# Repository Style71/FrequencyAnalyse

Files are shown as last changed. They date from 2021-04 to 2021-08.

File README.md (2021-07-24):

# FrequencyAnalyse

## About

Analyzing three frequency components in an analog signal and transmitting to host using Bluetooth-UART.

This project consists of five independent directories:

- `STM32Firmware`, the firmware of the STM32F767 MCU on the PCB/fPCB, which analyzing three frequency components in an analog signal using FFT, and transmitting the frequency info to host using Bluetooth-UART. The project is a mixture of C, C++ and Assembly language, and it is configured/edited/built/debugged using VScode IDE and build with `make`, see `STM32Firmware/README.md` for detailed description.
- `Hardware`, the PCB projects of the PCB/fPCB board. There are two subdirectories in this directory, `Hardware/SignalAnalyseV1.0` is the PCB project of prototype board, which is used for circuit validation and firmware development; `Hardware/SignalAnalyseV3.0.pdf` is the PCB project of the final fPCB board.
- `JavaProgram`, the Java project for the validation of the communication protocol parsing algorithm, see `JavaProgram/README.md` for detailed description.
- `Simulation`, Multisim simulation project of the envelope detector and bandpass filter circuit.
- `AndroidProject`, the Android program for time-frequency graph plotting and channel enable.
- `Doc`, documents about the signal processing algorithm used in this project, about the code structure and third-party API used in the firmware, about the PCB design consideration and circuit simulation results, and some technical notes during coding.

## Code download

There are two branches in this git repository:

- `master`-- Firmware for SignalAnalyseV1.0 prototype board.
- `V3.0`-- Firmware for SignalAnalyseV3.0 fPCB board, this branch is the final version of the entire project, use this branch as default. 

Use the following command to clone the project to your local host.

```bash
git clone https://github.com/Style71/FrequencyAnalyse.git
git submodule update --init --recursive
git checkout V3.0
```

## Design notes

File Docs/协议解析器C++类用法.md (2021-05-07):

# 协议解析器类用法

位置：`Message.cpp: ProtocolStream`

- 先根据你的程序框架，修改以下函数的具体实现：

  ```cpp
  void putchars(const char *pucArray, int size);
  void recv_frequency_info(uint8_t channel, WavePara &wave);
  void recv_battery_info(BatteryStatus &battery);
  ```

  其中`putchars`实现将指定数量的bytes通过蓝牙发送给下位机；`recv_frequency_info`实现你期望的收到频率报文后的程序行为；`recv_battery_info`实现你期望的收到电池状态报文后的程序行为。

- 将接收到的数据Bytes流输入给函数：

  ```cpp
  uint8_t ParsingMessage(uint8_t *msg, uint8_t len);
  ```

大功告成！

`type.h`文件定义了程序使用到的基本数据结构；

`DataStructure.cpp`/`DataStructure.h`实现了一个队列模板类，用于`ProtocolStream`类中的FIFO。你可以用Java的标准类替换。

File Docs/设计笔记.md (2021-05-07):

# 设计笔记

**注意**：本文描述的固件程序对应`FrequencyAnalyseV3.0`，硬件对应`SignalAnalyseV3.0`。

## 工程中使用`CMSIS-DSP`库

**CMSIS**(Cortex Microcontroller Software Interface Standard)提供了一个Cortex®-M系列处理器使用的通用信号处理函数库**CMSIS-DSP**，函数代码开源，可用两种方式调用：

1. 使用预先编译好的`.Lib`文件
   - 在Keil中点击add package，CMSIS DSP，工程列表里将出现一个...，自动包含对应的库文件。本次设计使用的Cortex-M7内核包含双精度浮点单元，工程使用Little endian顺序，因此使用的库为`arm_cortexM7lfdp_math.lib`(Cortex-M7, Little endian, Double Precision Floating Point Unit);
   - 在使用到CMSIS DSP库中函数的`.cpp`文件中包含头文件
  ```cpp
  #include "arm_math.h"
  ```
2. 自行编译`.Lib`文件，并在工程中包含该库文件
   
   - The library installer contains a project file to rebuild libraries on MDK toolchain in the `CMSIS\DSP_Lib\Source\ARM` folder.
   
     - arm_cortexM_math.uvprojx
   
     The libraries can be built by opening the arm_cortexM_math.uvprojx project in MDK-ARM, selecting a specific target, and defining the optional preprocessor macros detailed above.

### 使用`arm_biquad_cascade_df1_f32`函数注意

使用前需要先调用初始化函数：

```cpp
void arm_biquad_cascade_df1_init_f32(arm_biquad_casd_df1_inst_f32 *S, uint8_t numStages, float32_t *pCoeffs, float32_t *pState)
```

其中结构体`arm_biquad_casd_df1_inst_f32`定义为：

```cpp
typedef struct
{
  uint32_t numStages; /**< number of 2nd order stages in the filter.  Overall order is 2*numStages. */
  float32_t *pState;  /**< Points to the array of state coefficients.  The array is of length 4*numStages. */
  float32_t *pCoeffs; /**< Points to the array of coefficients.  The array is of length 5*numStages. */
} arm_biquad_casd_df1_inst_f32;

```

第一次使用时犯了一个错误，我在滤波器的初始化函数中创建了局部数组`Coeffs`、`initState`，用于初始化定义在全局的滤波器结构体`IIRFilterS`：

```cpp
static arm_biquad_casd_df1_inst_f32 IIRFilterS;

void InitFilter()
{
  float Coeffs[5 * STAGE_NUM];
  const float initState[4 * STAGE_NUM] = {0};
  // Initialise a 11-order Butterworth IIR filter with 120Hz passband and 200Hz stop frequency.
  for (int i = 0; i < STAGE_NUM; i++)
  {
    for (int j = 0; j < 3; j++)
      Coeffs[j + i * 5] = Gain[i] * NUM[i][j] / DEN[i][0];
    Coeffs[3 + i * 5] = -DEN[i][1] / DEN[i][0];
    Coeffs[4 + i * 5] = -DEN[i][2] / DEN[i][0];
  }
  arm_biquad_cascade_df1_init_f32(&IIRFilterS, STAGE_NUM, Coeffs, (float*) initState);
}
```

使用时发现滤波器的输出不正常，DEBUG时观察到`IIRFilterS->pCoeffs`和`IIRFilterS->pState`始终在非人为地改变，一开始还怀疑是DMA的目标地址、传输长度设置不对导致了全局变量`IIRFilterS`发生非人为地改变，后来才注意到`arm_biquad_casd_df1_inst_f32`的定义，`pCoeffs`、`pState`仅仅保留了一个指针，并没有对数据进行硬复制，也没有一个真正存储`pCoeffs`和`pState`的空间，如果我使用局部数组初始化，当`InitFilter()`函数退出后，`Coeffs[5 * STAGE_NUM]`、`initState[4 * STAGE_NUM]`的空间就被销毁了。

正确的使用方式是：定义全局数组用于存放滤波器系数和状态，然后在初始化函数中让指针`pCoeffs`、`pState`指向这两个数组。

```cpp
arm_biquad_casd_df1_inst_f32 IIRFilterS;
static float Coeffs[5 * STAGE_NUM];
static float initState[4 * STAGE_NUM] = {0};

void InitFilter()
{
  // Initialise a 11-order Butterworth IIR filter with 120Hz passband and 200Hz stop frequency.
  for (int i = 0; i < STAGE_NUM; i++)
  {
    for (int j = 0; j < 3; j++)
      Coeffs[j + i * 5] = Gain[i] * NUM[i][j] / DEN[i][0];
    Coeffs[3 + i * 5] = -DEN[i][1] / DEN[i][0];
    Coeffs[4 + i * 5] = -DEN[i][2] / DEN[i][0];
  }
  arm_biquad_cascade_df1_init_f32(&IIRFilterS, STAGE_NUM, Coeffs, initState);
}
```

这种实现方法就很奇怪，封装得不够好，要是使用者不清楚函数的实现，就很容易出错。虽然在滤波器实现之前，编程者并不知道滤波器有几阶，由于没有堆空间，不能使用动态内存分配，所以定义结构体`arm_biquad_casd_df1_inst_f32`时并不能指定`pCoeffs`、`pState`的数组大小，但是，滤波器的阶数完全可以在编译时确定，因此可以使用宏定义在编译时分配好`pCoeffs`、`pState`的空间。

### 使用`arm_rfft_fast_f32`函数注意

使用前需要先调用初始化函数：

```cpp
arm_status arm_rfft_init_f32(arm_rfft_instance_f32 *S, arm_cfft_radix4_instance_f32 *S_CFFT, uint32_t fftLenReal, uint32_t ifftFlagR, uint32_t bitReverseFlag)
```

初始化方式为：

```cpp
arm_rfft_fast_instance_f32 S;

void some_function()
{
    if (arm_rfft_fast_init_f32(&S, N) == ARM_MATH_ARGUMENT_ERROR)
        Error_Handler();
}
```

注意结构体`arm_rfft_fast_instance_f32`一定要放在全局，

## 计时器TIM的使用

本工程仅使用一个32-bit 的计时器TIM2，用于产生一个4kHz的方波信号作为**ADC1**的采样触发信号。具体配置如下：

- 

## STM32 使用DMA传送ADC转换数据

本例程使用**TIM2**产生一个4kHz的方波信号作为**ADC1**的采样触发信号，ADC工作在单次采样模式下，采样完成后结果由**DMA2**传送到FIFO中，直至FIFO容量达到3/4时转存到数据保存区`ADCBuffer0[ADC_BUFFER_SIZE]`和`ADCBuffer1[ADC_BUFFER_SIZE]`中，DMA工作在Double buffer mode下，双缓存模式将自动使能Circular mode，在该模式下，当传输计数器`DMA_SxNDTR `降至0后，会自动重载到设定值，同时DMA目标地址切换到另一个buffer。

第一次配置使用时发现：开始运行ADC后，`DMA_SxNDTR` 逐渐降至0并自动重载到设定值`ADC_BUFFER_SIZE`，然而却再也不会下降，FIFO、buffer中的数据也不再更新。此时重新发起ADC转换，DMA也不会传送数据。仔细阅读Manual，发现ADC的控制寄存器`ADC_CR2`的bit 9 `DDS `控制DMA计数至0后ADC是否继续产生新的传送请求：

At the end of the last DMA transfer (number of transfers configured in the DMA controller’s DMA_SxNTR register):

- No new DMA request is issued to the DMA controller if the DDS bit is cleared to 0 in the ADC_CR2 register (this avoids generating an overrun error). However the DMA bit is not cleared by hardware. It must be written to 0, then to 1 to start a new transfer. 
- Requests can continue to be generated if the DDS bit is set to 1. This allows configuring the DMA in double-buffer circular mode.

在使用**HAL**库时，若要使能`DDS`位，需要作如下初始化：

```cpp
hadc1.Init.DMAContinuousRequests = ENABLE;
```

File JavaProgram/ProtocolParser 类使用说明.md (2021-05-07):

# ProtocolParser 类使用说明

## 功能描述

- `ProtocolParser`类实现了对满足`FrequencyAnalyseV3.0`协议规范的数据流的**连接**、**解析**与**校验**;
- 封装了报文发送函数，可以方便地使用`ProtocolParser`类接口函数，**发送**满足协议规范的报文。

## 函数接口

### 类构造函数

- ```java
  public ProtocolParser();
  ```
  类构造函数，程序开始时创建类的实例即可:
  
  ```java
  ProtocolParser parser = new ProtocolParser();
  ```
  
  一个数据流可以同时feed多个解析类，但一个解析类只用于一个数据流的解析。
  
### 数据接收相关函数

- ```java
  public byte ParsingMessage(byte[] msg, int len) 
  ```
  数据输入流解析函数。该函数获取数据流输入，每次的输入数据可以是任意长度的byte，可以是截断的报文，只要输入的byte是**保序**的，函数内部会对输入数据进行缓存和连接；当确认接收到一个完整报文时，函数会自动解析报文，校验报文正确性，并调用对应报文的接收处理函数，见下表：
  
  | 报头                   | 报文内容              | 调用函数名                                              |
  | ---------------------- | --------------------- | ------------------------------------------------------- |
  | `0x51`、`0x52`、`0x53` | 3个频率通道的频率数据 | `void frequency_callback(int channel, WavePara freq)`   |
  | `0x59`                 | 电池电量状态          | `void battery_callback(BatteryStatus Batt)`             |
  | `0x5F`                 | 3个频率通道的使能指令 | `void channel_enable_callback(boolean[] channelEnable)` |
  使用该函数时，只需将输入数据流以`byte[]`形式传递给函数，为应对并非`byte[]`中所有`byte`均为有效数据的情况，需要在函数第二个参数中指定输入的`byte[]`包含的有效数据长度，用法如下：
  
  ```java
  BufferedInputStream binInput = new BufferedInputStream(new FileInputStream("Data.dat"));
  ProtocolParser parser = new ProtocolParser();
  int byteRead;
  byte[] msg;
  
  while ((byteRead = binInput.available()) > 0) {
      msg = binInput.readNBytes(byteRead);
      parser.ParsingMessage(msg, byteRead);
  }
  ```
  
- ```java
  private void frequency_callback(int channel, WavePara freq)
  ```
  接收到一帧频率报文时回调的函数，使用时在该函数内部实现收到该报文时需要做出的响应。传入的数据类`WavePara`封装了通道`channel`（1~3）的频率信息。`WavePara`类定义如下：
  
  ```java
  class WavePara {
      public int t;
      public float freq;
      public float mag;
      public float freq_deriv;
  
      public WavePara() {
          t = 0;
          freq = 0;
          mag = 0;
          freq_deriv = 0;
      }
  };
  ```
  
- ```java
  private void battery_callback(BatteryStatus Batt)
  ```
  接收到一帧电池电量状态报文时回调的函数，使用时在该函数内部实现收到电量报文时需要做出的响应。传入的数据类`BatteryStatus`封装了所有电池的电量状态信息。`BatteryStatus`类定义如下：
  
  ```java
  class BatteryStatus {
      public int t;
      public short voltage;
      public short current;
      public byte capacity;
  
      public BatteryStatus() {
          t = 0;
          voltage = 0;
          current = 0;
          capacity = 0;
      }
  };
  ```
  
- ```java
  private void channel_enable_callback(boolean[] channelEnable)
  ```
  接收到一帧电池电量状态报文时回调的函数。该函数供嵌入式系统调用，响应手机端上位机发来的通道使能指令，Android端可不关注，保持该函数为空。
  
### 数据发送相关函数
- ```java
  public void send_channel_enable_info(boolean[] channelEnable) 
  ```
  以协议格式发送3个频率通道的使能指令报文。该函数由Android端上位机调用，`channelEnable[i] == false`时，接收到报文的下位机将禁能频率通道`i`，不再发送该通道的频率数据；`channelEnable[i] == true`时可再次使能。

- ```java
  public void send_frequency_info(int channel, WavePara wave)
  ```
  以协议格式发送3个频率通道的频率数据报文。该函数由嵌入式端调用，Android端不调用。
  
- ```java
  public void send_battery_info(BatteryStatus battery)
  ```
  以协议格式发送电池电量状态报文。该函数由嵌入式端调用，Android端不调用。
  
- ```java
  private void putc_callback(byte[] msg)
  ```
  输出数据流的实现函数。前文提及的3个报文发送函数都依赖于本函数实现字节流的发送。需要由函数使用者实现发送数据流的功能。输出数据存放于`byte[] msg`数组中，长度为`msg.length`，待发送的数据低地址先发送，高地址后发送，`msg[0]`->`msg[msg.length]`。

## 用法说明

对于Android端上位机，只**需实现**以下函数：

```java
private void frequency_callback(int channel, WavePara freq);
private void battery_callback(BatteryStatus Batt);
private void putc_callback(byte[] msg);
```

Android端与嵌入式端的数据流如下图：

ProtocolParser类信息流示意图

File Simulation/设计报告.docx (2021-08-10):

带通滤波器参数：

R_1 =1MΩ ， R_2 =10kΩ ， C_1 =160nF ， C_2 =4nF ，低截止频率 f_L =2πR_1 C_1 ≈1Hz ，高截止频率 f_H =2πR_2 C_2 ≈4kHz , 中心频率 f_C =√(f_L ∙f_H)≈63Hz 。

电压传递函数 H(s)=(R_1 C_1 s)/((R_1 R_2 C_1 C_2 )s^2 +(R_1 C_1 +R_1 C_2 +R_2 C_2 )s+1)

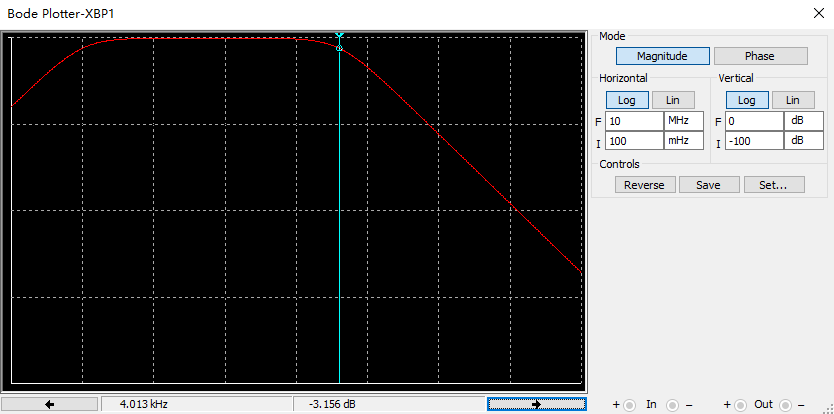
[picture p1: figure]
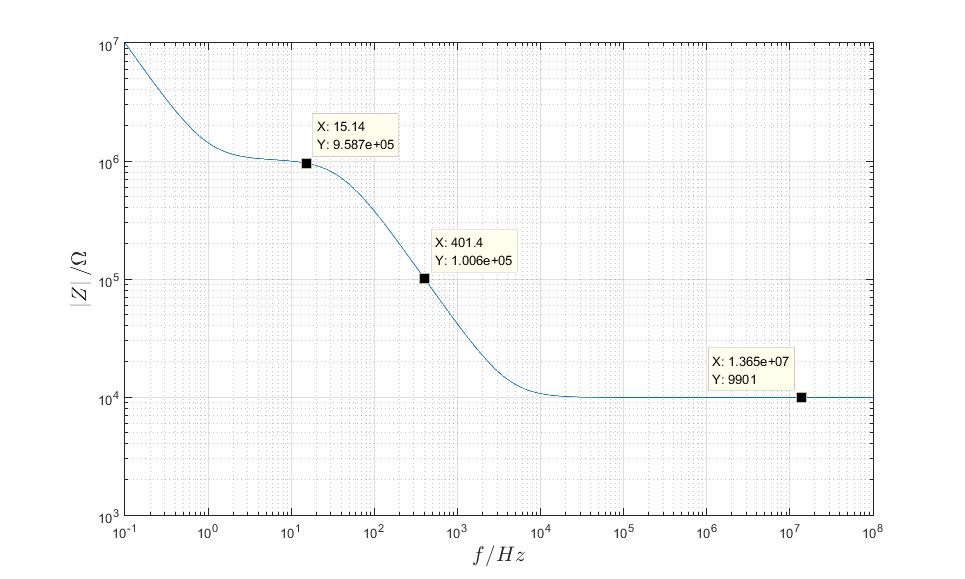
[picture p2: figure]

设采样频率 f_s =5kHz ，采样时窗 1s ，采样的同时计算前一秒数据FFT，采样数据按照double类型存储，保守估计需要 f_s ×8×4≈160kB 内存。

设采样频率为 f_s ，采样时窗为 T ，则采样点数 n=T∙f_s ，频率分辨率 δf=(f_s)/n=1/T ，即不确定性原理：信号频率不确定性 δf 与信号出现时间的不确定性 T 的乘积为常数。

T∙δf=1

假设一秒内需要对信号进行 k 次频率计算，则 T=1/k ， δf=k 。

设计要求以及对应的频率精度为：

信号频率 f | 采样时窗 T | 计算频率 k | 频率分辨率 δf
15~35Hz | 10s | 0.1 | 0.1Hz
60~100Hz | 2s | 0.5 | 0.5Hz
200~400Hz | 0.1s | 10 | 10Hz

若先验地认为信号频率变化缓慢，则可以将 T 提升，以降低 δf 。

f_s =4kHz

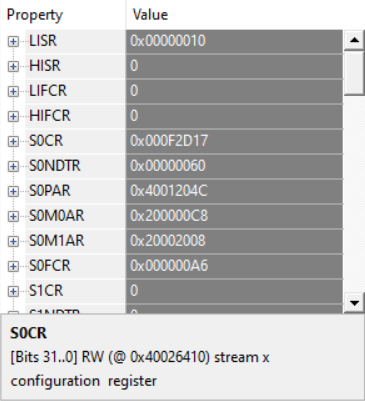
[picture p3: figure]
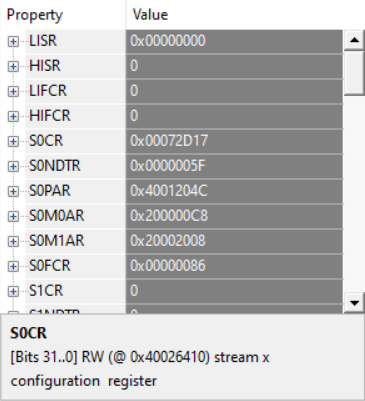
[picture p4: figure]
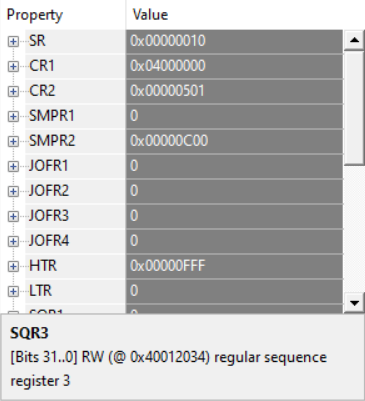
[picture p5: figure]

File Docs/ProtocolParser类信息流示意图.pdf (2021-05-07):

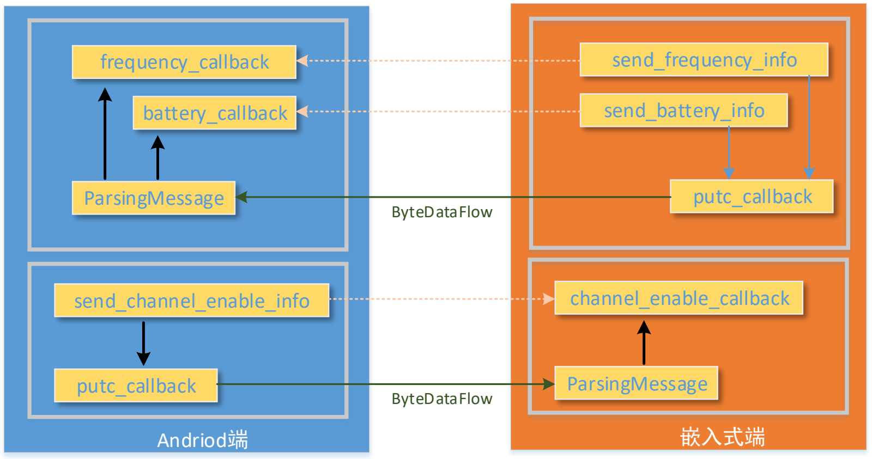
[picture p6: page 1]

Andriod

端 | 嵌入式端

putc

_callback

send

_channel

_enable

_info

putc

_callback

send

_frequency

_info

battery

_callback | send _battery

_info

frequency

_callback

ParsingMessage

ParsingMessage

channel

_enable

_callback

ByteDataFlow

ByteDataFlow

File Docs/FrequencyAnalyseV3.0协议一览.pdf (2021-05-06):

Head | Payload | Checksum | Type | TX Period | Note
byte[0] byte[1] byte[2] byte[3] byte[4] byte[5] byte[6] byte[7] byte[8] byte[9] byte[10] byte[11] byte[12] byte[13] byte[14] byte[15] byte[16] byte[17] byte[18]
System time/us | Frequency/Hz | Magnitude/V | Frequency Derivation/Hz
0x5A | 0x51 | uint32_t | float | float | float | bit XOR | 主动发送报文 0.128s | 180~420Hz Frequency Channel 1
0x5A | 0x52 | uint32_t | float | float | float | bit XOR | 主动发送报文 2.56s | 50~120Hz Frequency Channel 2
0x5A | 0x53 | uint32_t | float | float | float | bit XOR | 主动发送报文 10.24s | 10~40Hz Frequency Channel 3
Head | Payload | Checksum | Type | TX Period | Note
byte[0] byte[1] byte[2] byte[3] byte[4] byte[5] byte[6] byte[7] byte[8] byte[9] | byte[10] | byte[11]
System time/us | Voltage/mV | Current/mA Capacity/percent
0x5A | 0x59 | uint32_t | uint16_t | uint16_t | uint8_t | bit XOR | 主动发送报文 | 1.00s | 系统电量使用情况
Head | Payload | Checksum | Type | Note
byte[0] byte[1] | byte[2] | byte[3] | byte[4] | byte[5]
Channel 1 Enable Channel 2 Enable Channel 3 Enable
0x5A | 0x5F | uint8_t | uint8_t | uint8_t | bit XOR | 接收报文 | 通道使能字节，1：使能，0：禁能
1.报文采用Little Endian模式发送、接收，先发送低位字节，再发送高位字节，byte[0]->byte[n]； 2.数据段低位在前，高位在后，例如uint32_t类型的System time，其值为2760643741（0xA48C149D），byte[2]=0x9D，byte[5]=0xA4； 3.数据校验位Checksum为Head+Payload所有位的异或XOR。

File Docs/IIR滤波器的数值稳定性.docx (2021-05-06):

IIR滤波器的数值稳定性

在微控制器上实现同一个IIR（Infinite Impulse Response，无限冲激响应）滤波器时，不同的实现方式可能出现不同的数值稳定性问题，对于部分病态情况，会导致滤波器输出严重偏离真实值。现举例来说：

系统采样率 f_s =4kHz ，欲设计一个LPF（Low Pass Filter，低通滤波器），通带频率 f_p =120Hz ，截止频率 f_(stop) =200Hz ，截止频率衰减 A_(stop) =40dB 。令 u[n] 表示输入， y[n] 表示输出，对应的频域表示分别为 U(z) 、 Y(z) 。使用Matlab fdatool 给出一个11阶的Butterworth滤波器：

(Y(z))/(U(z))=H(z)=G(a_0 +a_1 z^(-1) +⋯+a_11 z^(-11))/(b_0 +b_1 z^(-1) +⋯+b_11 z^(-11)) (1-1)

其中，分子系数 a=[1, 11, 55, 165, 330, 462, 462, 330, 165, 55, 11, 1] ，

分母 b=[, 1.0000, -9.5923, 41.9040, -110.0381, 192.9809, -237.3184,, 208.8062, -131.4397, 58.0076, -17.0926, 3.0264, -0.2439]

增益 G=5.2262×10^(-12) 。

频率响应、单位冲击响应如图.1-a、图.1-b：

图.1-a 频率响应 H(z)

图.1-b 单位冲击响应 h[n]

该IIR滤波器的时域表示为：

b_0 y[n]+b_1 y[n-1]+⋯+b_11 y[n-11]

=G(a_0 u[n]+a_1 u[n-1]+⋯+a_11 u[n-11]) (1-2)

第一种滤波器的实现方法，可根据递推关系式(1-2)，使用 22 个中间状态值临时存储 y[n-1], y[n-2],⋯, y[n-11],u[n-1], u[n-2], ⋯,u[n-11] ，实现该IIR滤波器。

另一种是状态空间实现方案。该11阶Butterworth滤波器只有11个独立状态，令 x[n]∈R^11 ，采用可控标准型实现：

{x[n+1]=Ax[n]+Bu[n]y[n]=Cx[n]+Du[n] (1-3)

其中 A∈R^(11×11) ， B∈R^(11×1) ， C∈R^(1×11) ， D∈R^(1×1) ，

A=[-(b_1)/(b_0), -(b_2)/(b_0), -(b_3)/(b_0)1, 0, 00, 1, 0, ⋯, -(b_10)/(b_0), -(b_11)/(b_0)0, 00, 0⋮, ⋱, ⋮0, 0, 00, 0, 0, ⋯, 0, 01, 0] ， B=[1, 0, 0⋯0, 0, 0]^T ，

C=G[a_1 -(a_0)/(b_0)b_1 , a_2 -(a_0)/(b_0)b_2 , a_3 -(a_0)/(b_0)b_3 ⋯a_9 -(a_0)/(b_0)b_9 , a_10 -(a_0)/(b_0)b_10 , a_11 -(a_0)/(b_0)b_11 ] ，

D=G(a_0)/(b_0)

计算得出 A 的第一行

A(1,:)=[, 9.5923, -41.9040, 110.0381, -192.9809, 237.3184, -208.8062, , 131.4397, -58.0076, 17.0926, -3.0264, 0.2439] 。

采用该状态空间实现方案，在Cortex-M7内核芯片上使用C++实现，数值类型采用32bit float，计算单位冲激响应 h[n] ，发现 h[n] 很快以指数发散了，如图.2。由于 u[n]=δ[n] ，由式(1-3)知， h[n] 发散意味着 x[n] 发散了，将 x_1 [n] 绘出，如图.3。

图2. 使用状态空间实现的IIR滤波器，其单位冲击响应 h[n]

图3. 单位冲击 δ[n] 下的状态变化 x_1 [n]

由于 x[1]=[1, 0, 0⋯0, 0, 0]^T ， u[n]=0 (n≥1) ，故 x[n+1]=A^n x[1]=A^n (:,1) ， x[n+1] 发散意味着矩阵 A^n 的第一列发散了。将 A 分解为Jordan标准型，

A=P∙J∙P^(-1) ，A^n =P∙J^n ∙P^(-1)

J^n =[J_1^n , ⋯, 0⋮, ⋱, ⋮0, ⋯, J_k^n ] ， J_i^n =[λ_i^n , C_n^1 λ_i^(n-1) , C_n^2 λ_i^(n-2) 0, λ_i^n , C_n^1 λ_i^(n-1) 0, 0, λ_i^n , ⋯, C_n^(m-1) λ_i^(n-m+1) C_n^(m-2) λ_i^(n-m+2) C_n^(m-3) λ_i^(n-m+3) ⋮, ⋱, ⋮0, 0, 0, ⋯, λ_i^n ]_(m×m)

A^n 发散也即 A 存在大于 0 的特征值。事实真的如此吗？使用Matlab计算 A 的Jordan标准型分解：

>> [P,J]=jordan(A)

得到 A 的 11 个特征值：

λ=[, 0.8173, 0.8229±0.0471i, 0.8395±0.0922i, 0.8670±0.1331i,, 0.9052±0.1672i, 0.9530±0.1916i]

模 |λ_i | 竟然均小于1！如果使用Matlab采用 P∙J^n ∙P^(-1) 计算 A^n ，发现 A^n 也是收敛的；而若直接用Matlab指令A^n计算 A^n ，结果发散……

基于如下原因，更倾向于相信 P∙J^n ∙P^(-1) 的计算结果：

- 使用 A^n =P∙J^n ∙P^(-1) 计算 x[n+1] ，进而计算 y[n+1]=Cx[n+1] ，得到的结果与Matlab计算的单位冲激响应 h[n] 结果一致；
- 理论上使用 A^n =P∙J^n ∙P^(-1) 方式的计算结果具有更高的数值稳定性。

那为何使用微控制器、Matlab的A^n指令直接计算 A^n 结果发散了？原因在于矩阵 A 病态(ill-conditioned)。使用矩阵奇异值分解计算 A 的奇异值：

A=PΣQ

Σ=[σ_1 , 00, σ_2 , ⋯, 00⋮, ⋱, ⋮0, 0, ⋯, σ_11 ] ， σ_1 =414.8 ， σ_2 =σ_3 =⋯=σ_10 =1 ， σ_11 =5.88×10^(-4) ，

PP^T =QQ^T =I_11

矩阵 A 的条件数 cond(A)=7.0543×10^5 。由于变量使用浮点数存储、计算存在舍入误差，设 x[n+1]=A[x[n]+δx[n]]=x[n+1]+Aδx[n] ，计算相对误差增量的上界

sup(‖δx[n+1]‖)/(‖x[n+1]‖)=sup(‖Aδx[n]‖)/(‖Ax[n]‖)=(sup‖Aδx[n]‖)/(inf‖Ax[n]‖)=(σ_1 ‖δx[n]‖)/(σ_11 ‖x[n]‖)=cond(A)(‖δx[n]‖)/(‖x[n]‖)

因此每次计算矩阵乘法，将可能使状态变量 x[n] 的相对误差增加 cond(A) 倍。

如果换用递推关系式(1-2)的实现方案呢？此时计算过程等价于选取状态变量 x[n]=[u[n-1], u[n-2], ⋯,u[n-11], y[n-1], y[n-2],⋯, y[n-11]]∈R^22 ，

A=[0_(1×11) I_10 , 0_(10×1) , 0_(11×11) G/(b_0)a(2:11)0_(10×11) , -1/(b_0)b(2:11)I_10 , 0_(10×1) ]

此时 rank(A)=21 ， A 的奇异值为： σ_1 =414.8 ， σ_2 =σ_3 =⋯=σ_20 =1 ， σ_21 =5.88×10^(-4) ， cond(A)=7.0543×10^5 。当 n≥12 后， x_1 [n]=⋯=x_11 [n]=0 ，计算过程变为了：

{x(12:22)[n+1]=A(12:22,12:22)x(12:22)[n]y[n]=x(12)[n]

此时的 A(12:22,12:22) 就是上一种方式中的 A ，仅仅改变了状态变量为输出变量，按照之前的分析，这种实现方式与第一种相比并没有改善数值稳定性，也是有可能发散的。

当然，使用Matlab计算的结果， y[n] 是收敛的；第一种方案在Cortex-M7内核芯片上采用64bit double数值类型计算，结果也是收敛的。然而，没有改变问题本身的数值特性，仅依靠提高运算精度，算法是不可靠的。

合适的做法是将传递函数分解为多个二阶传递函数的乘积。如本问题，可以分解为5个二阶滤波器和1个一阶滤波器的级联，每个滤波器的传递函数为：

H_i (z)=(b_(i0) +b_(i1) z^(-1) +b_(i2) z^(-2))/(1-a_(i1) z^(-1) -a_(i2) z^(-2))

实现时使用 u[n-1], u[n-2],y[n-1], y[n-2] 作为状态变量以提高数值稳定性，这种实现方案在CMSIS-DSP库中被称为“Biquad Cascade IIR Filters Using Direct Form I Structure”，如图4所示。

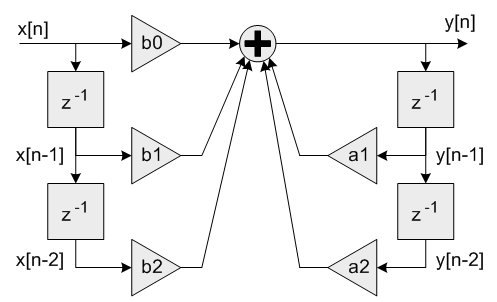
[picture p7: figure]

图4. 二阶IIR滤波器Direct Form I结构

6个滤波器的系数分别为：

a_i =[1, 2, 1] ， i=1, 2,⋯,5 ， a_6 =[1, 1] ；

b_1 =0.01043620054×[1, -1.901244521, 0.9429892898] ，

b_2 =0.009894934483×[1, -1.802637815, 0.842217505] ，

b_3 =0.009464552626×[1, -1.72423172, 0.7620899677] ，

b_4 =0.009154595435×[1, -1.667764425, 0.7043827772] ，

b_5 =0.00896828156×[1, -1.633822203, 0.6696953177] ，

b_6 =0.09437258542×[1, -0.8112547994] 。

若从状态空间的角度看计算过程，每个滤波器的系数矩阵 A_i 为：

A_i =[0, 01, 0, 0, 00, 0b_(i1) , b_(i2) 0, 0, a_(i1) , a_(i2) 1, 0]

计算每个矩阵 A_i （ i=1,2,⋯,5 ）的右下子阵 A_i (3:4,3:4) 的条件数，分别为：

Cond(A_1 (3:4,3:4))=5.66 ，

Cond(A_2 (3:4,3:4))=5.71 ，

Cond(A_3 (3:4,3:4))=5.80 ，

Cond(A_4 (3:4,3:4))=5.90 ，

Cond(A_5 (3:4,3:4))=5.98 。

该计算问题是良态的。

思考：

使用 n 个2阶矩阵级联构成一个 2n 阶的滤波器，内部独立的状态变量仍然只有 2n 个，整个计算过程可以用一个 2n 阶的状态方程等效替代。对于所有 2n 阶的状态空间实现，由于都是最小实现，相互间可以用一个非奇异线性变换相互转化， A=T^(-1) AT 。因此原方案是病态的，之所以换用Direct Form I结构实现后变为良态的，就是使用了一个变换 T ，使得条件数 cond(A)=cond(T^(-1) AT) 显著降低。

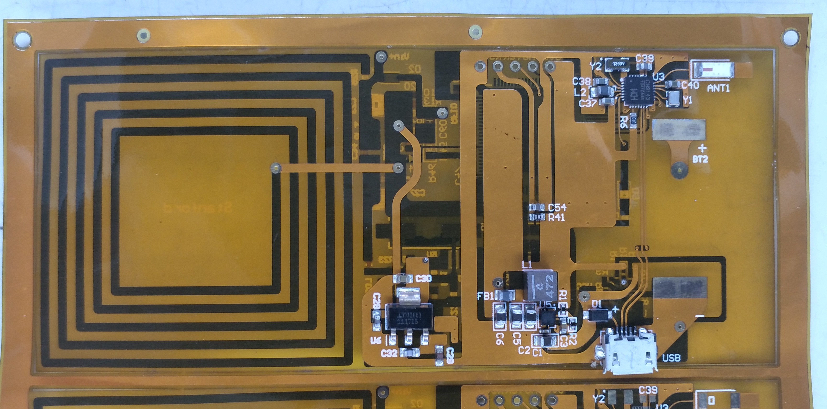
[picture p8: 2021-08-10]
Hardware/SignalAnalyseV3.0/T-N48W156855A-02.jpg

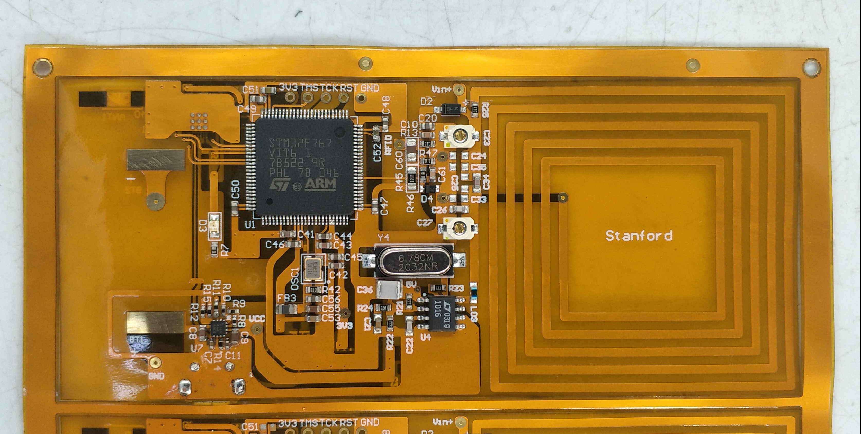
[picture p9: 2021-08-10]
Hardware/SignalAnalyseV3.0/T-N48W156855A-01.jpg

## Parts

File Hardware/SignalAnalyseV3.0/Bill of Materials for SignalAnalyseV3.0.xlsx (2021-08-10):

Designator | Comment | Description | Footprint | Manufacturer | Part Number | Quantity
C4, C5, C6 | Cap 47μF | 多层陶瓷电容器MLCC - SMD/SMT 0805 10V 47uF X5R 20% T: 1.25mm | 0805 | TDK | C2012X5R1A476M125AC | 3
C1 | Cap 22μF | 多层陶瓷电容器MLCC - SMD/SMT 0805 35VDC 22uF 20% X5R 1.25mm | 0805 | TDK | C2012X5R1V226M125AC | 1
C2 | Cap 2.2nF | 多层陶瓷电容器MLCC - SMD/SMT 0402 2200pF 50volts X7R 10% | 0402 | MuRata | GRM155R71H222KA01D | 1
C7 | Cap 1.3nF | 多层陶瓷电容器MLCC - SMD/SMT 0402 1.3nF 50VDC X7R 5% | 0402 | MuRata | GRM155R71H132JA01D | 1
C11 | Cap 100nF | 多层陶瓷电容器MLCC - SMD/SMT 0402 100nF 10VDC X5R 5% | 0402 | MuRata | GRM155R61A104JA01D | 1
C3 | Cap 470nF | 多层陶瓷电容器MLCC - SMD/SMT 0603 0.47uF 6.3volts X5R 10% | 0603 | MuRata | GRM188R60J474KA01D | 1
C61 | Cap 33nF | 多层陶瓷电容器MLCC - SMD/SMT 0603 0.033uF 6.3volts U2J 5% | 0603 | MuRata | GRM1887U0J333JA01D | 1
C10 | Cap 47nF | 多层陶瓷电容器MLCC - SMD/SMT 47nF+/-10% 50V X7R 1608 | 0603 | SAMSUNG | CL10B473KB8NNNC | 1
C20 | Cap 100nF | 多层陶瓷电容器MLCC - SMD/SMT 100nF+/-10% 50V X7R 1608 | 0603 | SAMSUNG | CL10B104KB8NNNC | 1
C21 | Cap 820p | 多层陶瓷电容器MLCC - SMD/SMT 0603 820pF 100volts X7R 5% | 0603 | MuRata | GRM188R72A821JA01D | 1
C22 | Cap 200p | 多层陶瓷电容器MLCC - SMD/SMT 0603 200pF 100volts C0G 2% | 0603 | MuRata | GRM1885C2A201GA01D | 1
C23, C27 | Cap Var | Trimmer Capacitors - Ceramic Dielectric, 8 pF to 40 pF, 350 V | Variable_Capacitor_JZ400HV1 | Knowles | JZ400HV | 2
C24, C25 | Cap 100pF | 多层陶瓷电容器MLCC - SMD/SMT 0201 100pF 50volts C0G +/-2% | 0603 | MuRata | GRM0335C1H101GA01D | 2 | Capacitor_for resonance | 无需贴片
C26 | Cap 300pF | 多层陶瓷电容器MLCC - SMD/SMT 0603 300pF 50volts C0G 2% | 0603 | MuRata | GRM1885C1H301GA01D | 1 | Capacitor_for resonance
C34 | Cap 33pF | 多层陶瓷电容器MLCC - SMD/SMT 0603 33pF 50volts C0G 5% | 0603 | MuRata | GRM1885C1H330JA01J | 1 | Capacitor_for resonance
C33, C35 | Cap 0~200pF | Do not place | 0603 |  |  | 2 | Capacitor_for resonance
C28, C39, C44, C45, C46, C47, C48, C49, C50, C54, C56 | Cap 100nF | 多层陶瓷电容器MLCC - SMD/SMT 0.1UF 16V 10% 0603 | 0603 | MuRata | GCM188R71C104KA37J | 11
C9, C29, C55 | Cap 10μF | 多层陶瓷电容器MLCC - SMD/SMT 10UF 25V 10% 0603 | 0603 | MuRata | GRM188R61E106KA73D | 3
C30 | Cap 22u | 多层陶瓷电容器MLCC - SMD/SMT 22UF 10V 20% 0603 | 0603 | MuRata | GRM187R61A226ME15J | 1
C32 | Cap 10n | 多层陶瓷电容器MLCC - SMD/SMT 0.01UF 25V 5% 0603 C0G | 0603 | MuRata | GRM1885C1E103JA01D | 1
C36 | Cap 100nF | 多层陶瓷电容器MLCC - SMD/SMT MLCC,1210,C0G,50V,0.1uF,2.5mm | 1210 | TDK | C3225C0G1H104JT000N | 1
C8, C41, C42, C43 | Cap 1μF | 多层陶瓷电容器MLCC - SMD/SMT 0603 1uF 25V X6S 10% | 0603 | MuRata | GRM188C81E105KAADD | 4
C53 | Cap 4.7μF | 多层陶瓷电容器MLCC - SMD/SMT 0603 4.7uF 25V X5R 20% | 0603 | MuRata | GRM188R61E475ME11J | 1
C37, C38, C40, C51, C52 | Cap 2.2μF | 多层陶瓷电容器MLCC - SMD/SMT CGA 0603 16V 2.2uF X5R 10% AEC-Q200 | 0603 | TDK | CGA3E1X5R1C225K080AC | 5
C60 | Cap 22μF | 多层陶瓷电容器MLCC - SMD/SMT 0805 25VDC 22uF 20% X5R 1.25mm | 0805 | TDK | C2012X5R1E226M125AC | 1
D1 | Diode | Surface Mount Schottky Power Rectifier, 1.0 AMPERES 20 VOLTS | SODFL3616X98N | ON Semiconductor | MBR120VLSFT1G | 1
D2 | Diode | Surface Mount Schottky Power Rectifier, 0.5 AMPERES 40 VOLTS | SOD3716X135N | ON Semiconductor | MBR0540T1G | 1
D3 | LED-Green | Green LEDs, 2V 20mA 570 nm | 0805 | Wurth Elektronik | 150080VS75000 | 1
D4 | TDZ3V0J | Zener Diode 3V | SOD323F | Nexperia | TDZ3V0J,115 | 1
FB1, FB3 | Ferrite Bead, 20Ohm@100MHz | WE-CBA SMT EMI Suppression Ferrite Bead | BEADC2012X110N | Wurth Elektronik | 782853200 | 2
L1 | Inductor 4.7 μH | Coilcraft Shielded Power Inductors | XGL4030 | Coilcraft | XGL4030-472MEC | 1
L2 | Inductor 22 μH | Multilayer Chip Ferrite Large Current Inductor | 0805 | microgate | MGFL2012F220 | 1
L03 | Inductor 220 nH | Chip Coils Inductor | 0603 | Murata | LQW18ANR22G00D | 1
R1 | Res 14.7KΩ ±1% | Resistor | 0402 | Vishay-Dale | CRCW040214K7FKED | 1
R2 | Res 4.7KΩ ±1% | Resistor | 0402 | Vishay-Dale | CRCW04024K70FKED | 1
R8 | Res 360KΩ ±1% | Resistor | 0402 | YAGEO | RC0402FR-07360KL | 1
R9 | Res 56KΩ ±1% | Resistor | 0402 | YAGEO | RC0402FR-0756KL | 1
R10 | Res 42.2KΩ ±1% | Resistor | 0402 | YAGEO | RC0402FR-0742K2L | 1
R11 | Res 47KΩ ±1% | Resistor | 0402 | YAGEO | RC0402FR-0747KL | 1
R12 | Res 147KΩ ±1% | Resistor | 0402 | YAGEO | RC0402FR-07147KL | 1
R14 | Res 2.2KΩ ±1% | Resistor | 0402 | YAGEO | RC0402FR-072K2L | 1
R15 | Res 34KΩ ±1% | Resistor | 0402 | YAGEO | RC0402FR-0734KL | 1
R13 | Res 12.7KΩ ±1% | Resistor | 0603 | YAGEO | RC0603FR-0712K7L | 1
R6 | Res 100KΩ ±1% | Resistor | 0603 | YAGEO | RC0603FR-07100KL | 1
R7, R42, R46 | Res 1KΩ ±1% | Resistor | 0603 | YAGEO | RC0603FR-071KL | 3
R21, R22, R23 | Res 2.2KΩ ±1% | Resistor | 0603 | YAGEO | RC0603FR-072K2L | 3
R24 | Res 22Ω ±1% | Resistor | 0603 | YAGEO | RC0603FR-0722RL | 1
R25 | Res 1Ω ±1% | Resistor | 0603 | YAGEO | RC0603FR-071RL | 1
R45 | Res 12KΩ ±2% | Resistor | 0805 | YAGEO | RC0805FR-0712KL | 1
R41, R47 | Res 10KΩ ±1% | Resistor | 0603 | YAGEO | RC0603FR-0710KL | 2
U1 | STM32F767VIT6 | ARM MCU 32-BITS | LQFP-100 | ST | STM32F767VIT6 | 1
U3 | CH9143 | Bluetooth-LowEnergy & UART & USB Mutual Transport | QFN28_4X4 | WCH | CH9143 | 1 | 预量产样片，需从南京沁恒WCH官网购买
U4 | LT1016 | Ultra Fast Precision Comparator | SOIC 8-Lead | Linear Technology/Analog Devices | LT1016CS8#PBF | 1
U5 | XPS62912RPUR | 3-V to 17-V, 2-A/3-A Low Noise and Low Ripple Buck Converter with Integrated Ferrite Bead Filter Compensation | VQFN-HR 1mm | Texas Instruments | XPS62912RPUR | 1 | 预量产样片，需从TI官网购买
U6 | LT1117IST-5#PBF | 800mA Low Dropout Positive Regulators Fixed 5V | SOT-223 | Linear Technology/Analog Devices | LT1117IST-5#PBF | 1
U7 | LM73100RPWR | 2.7 - 23 V, 5.5 A Integrated Ideal Diode with Input Reverse Polarity and Overvoltage Protection | VQFN-HR-10_2X2_TEX | Texas Instruments | LM73100RPWR | 1
ANT1 | Ceramic Antenna | 2.4GHz Antenna - 2.4GHz, 5GHz, Bluetooth, WiFi, WLAN, Zigbee | ANTC5020 | Johanson | 2450AT42A100E | 1
USB | Micro USB Jack | USB连接器 Micro USB Type AB Connectors | Jack (Female) | Wurth Elektronik | 629105150921 | 1
OSC1 | 16MHz | 标准时钟振荡器 SMD XTAL OSC 16MHZ +/-50PPM -40~105C 250TR | SMD/SMT_3.2X2.5 | SEIKO EPSON | SG-310SCF 16.0000ML | 1
Y1 | 32MHz | Quartz Crystal Units YSX211SL 32MHZ-10PF-10PPM | SMD2016-4N | Yangxing Tech | X201632MMB4SI | 1
Y2 | 32.768KHz | Crystal Oscillator FC-135 32.768000KHZ-12.5PF-20PPM | FC-135 | SEIKO EPSON | Q13FC1350000400 | 1
Y4 | 6.78MHz | Industry standard SMD crystal HC49/4HSMX 6.780MHZ-20PF-30PPM | HC49/4HSMX | IQD | LFXTAL057410Bulk | 1

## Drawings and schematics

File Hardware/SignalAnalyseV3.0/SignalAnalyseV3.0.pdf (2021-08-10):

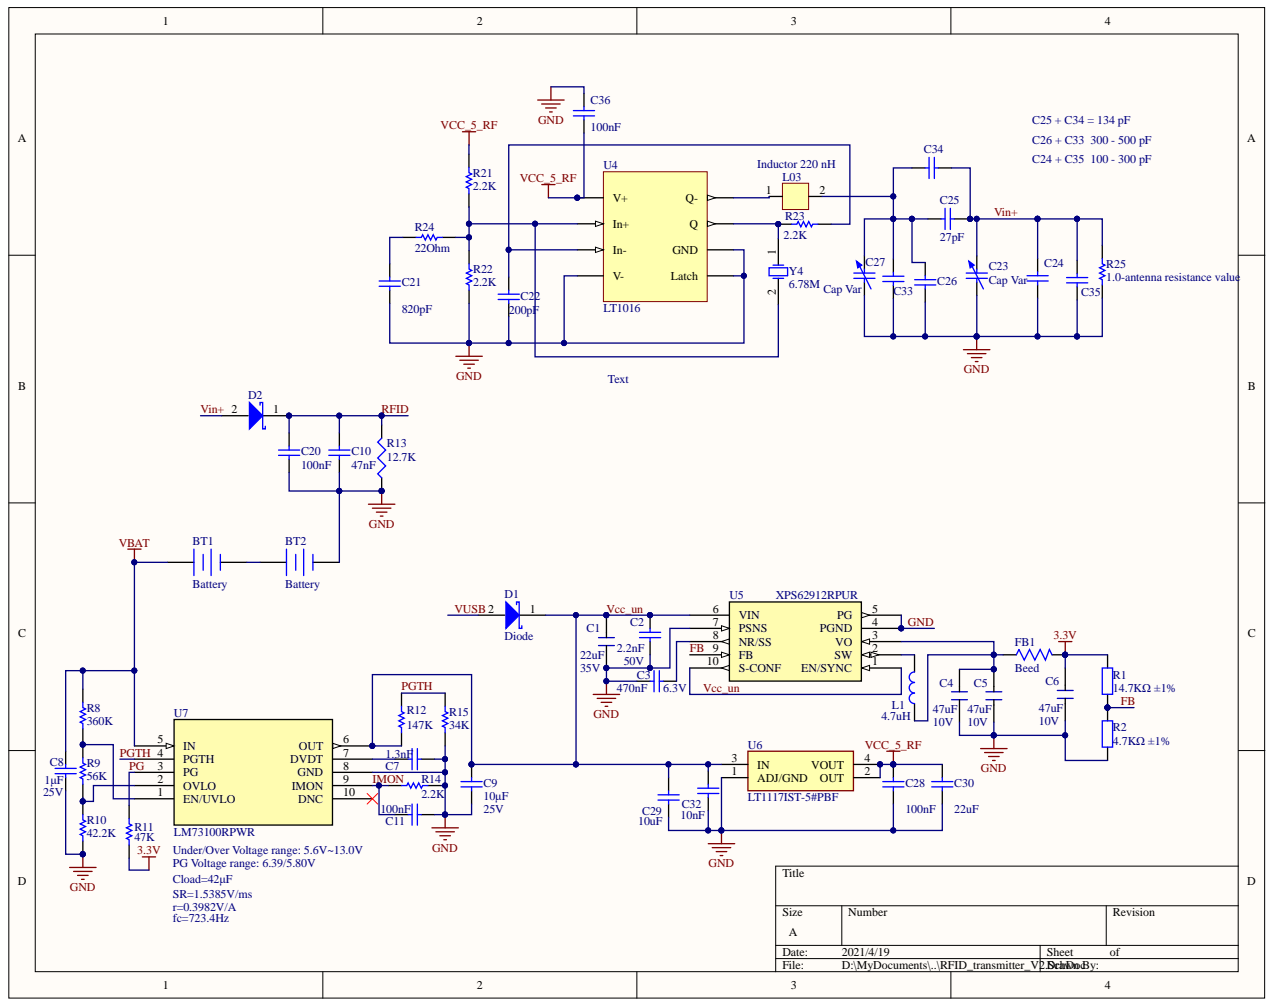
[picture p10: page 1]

2.2K | In-GND

V-Latch

Size A | Number | Revision

Date: 2021/4/19 | Sheet of
File: D:\MyDocuments\..\RFID_transmitter_V2.SchD Drawn By: oc

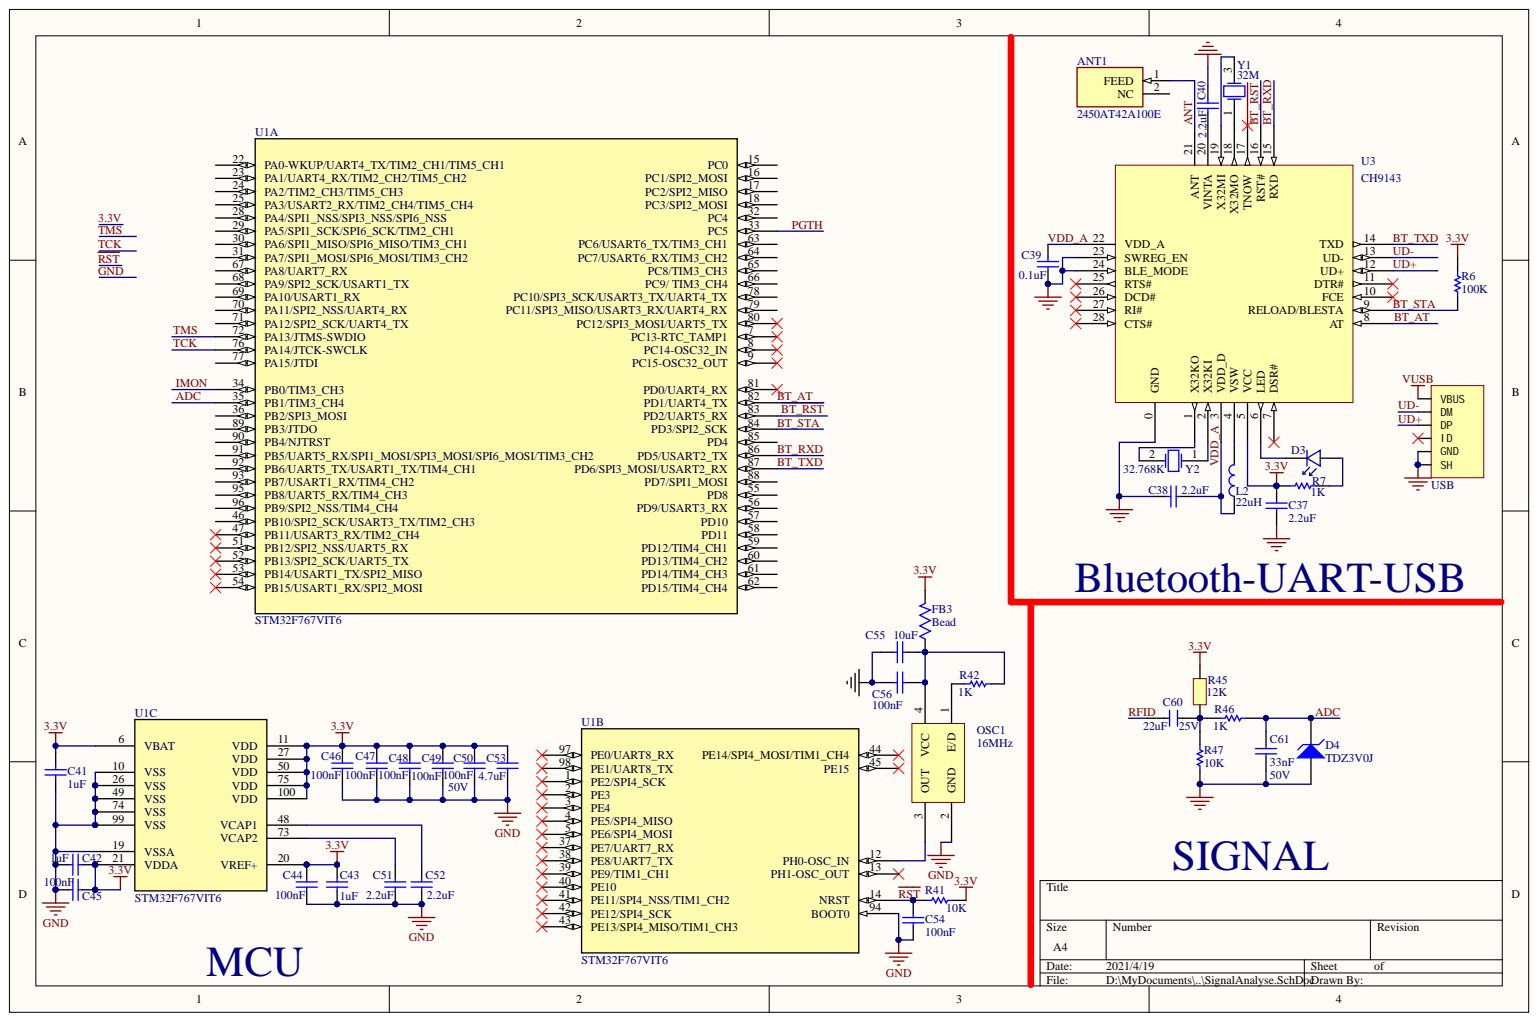
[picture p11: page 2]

SWREG_EN 23
BLE_MODE 24 RTS# 25

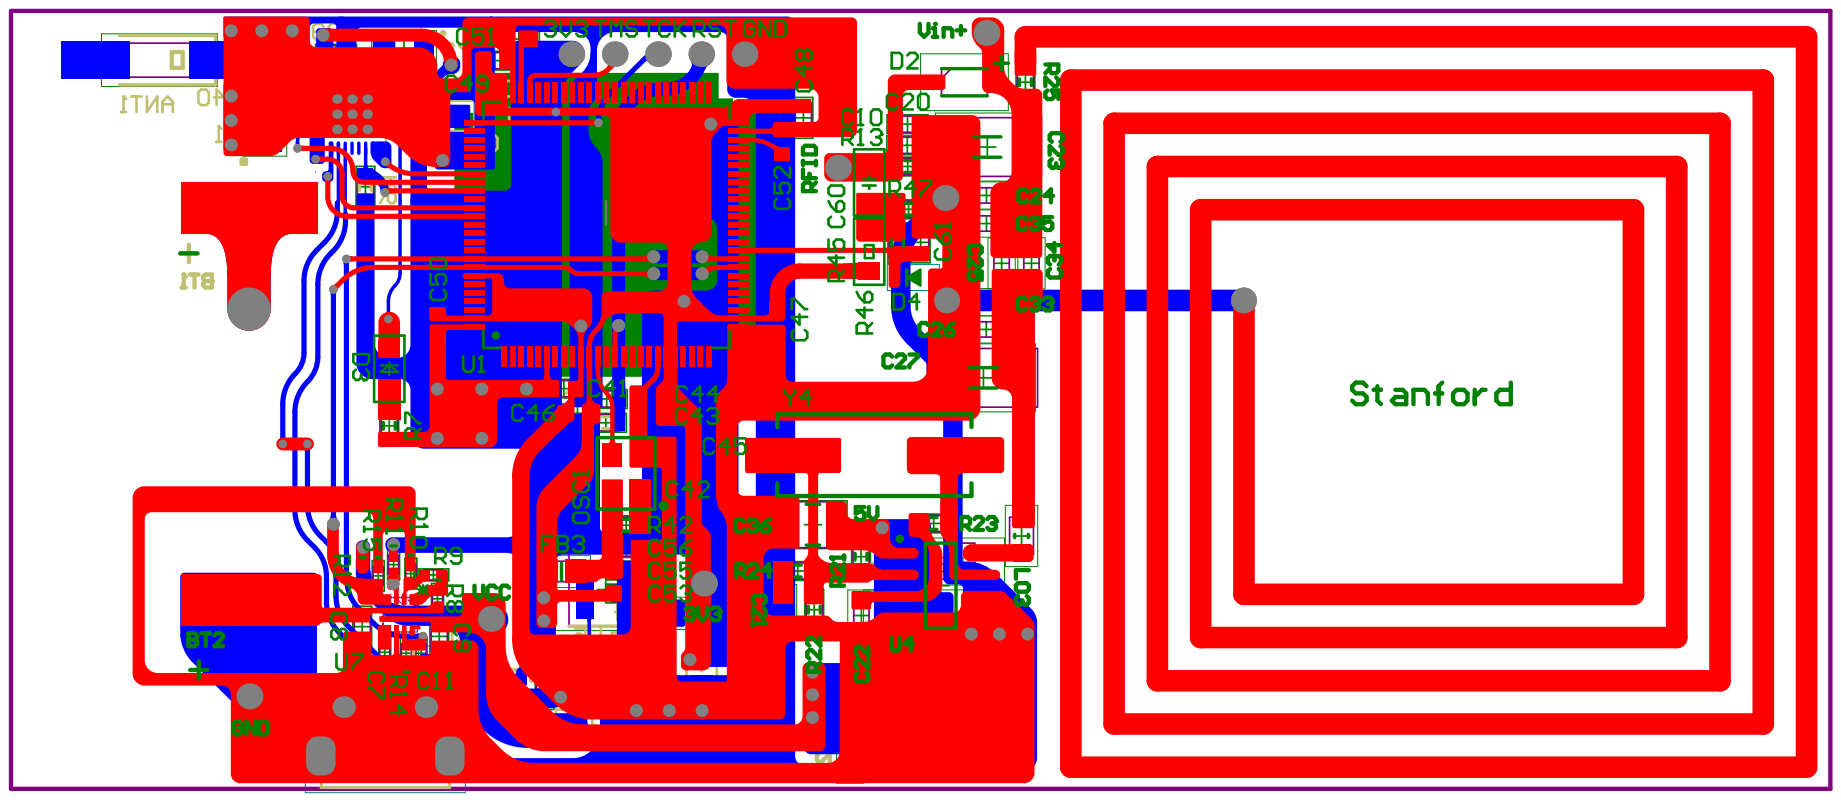
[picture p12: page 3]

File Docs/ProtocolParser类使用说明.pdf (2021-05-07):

# ProtocolParser 类使用说明

# 功能描述

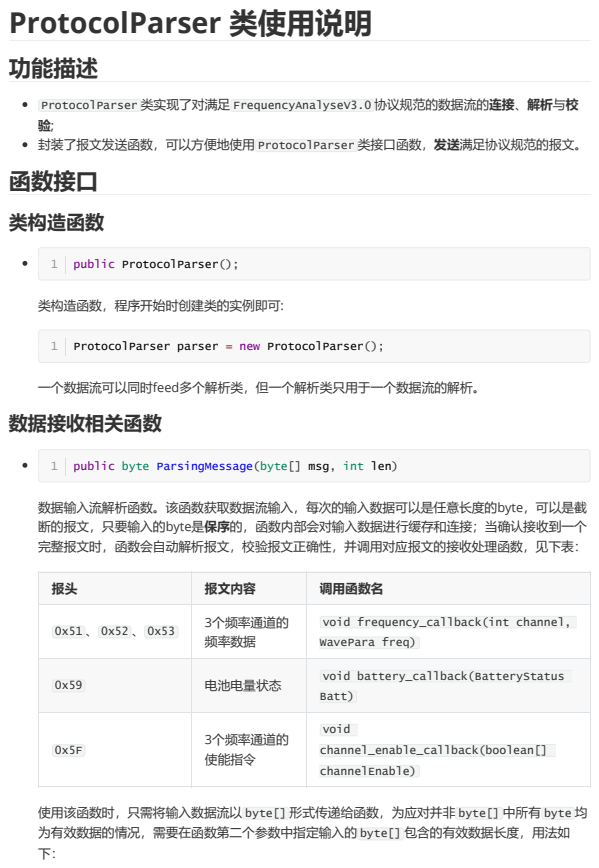
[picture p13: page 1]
类构造函数，程序开始时创建类的实例即可:; 一个数据流可以同时feed多个解析类，但一个解析类只用于一个数据流的解析。 数据接收相关函数; public ProtocolParser();; ProtocolParser parser = new ProtocolParser();; public byte ParsingMessage(byte[] msg, int len)

ProtocolParser 类实现了对满足 FrequencyAnalyseV3.0 协议规范的数据流的连接、解析与校
封装了报文发送函数，可以方便地使用 ProtocolParser 类接口函数，发送满足协议规范的报文。
函数接口
类构造函数

数据输入流解析函数。该函数获取数据流输入，每次的输入数据可以是任意长度的byte，可以是截
断的报文，只要输入的byte是保序的，函数内部会对输入数据进行缓存和连接；当确认接收到一个
完整报文时，函数会自动解析报文，校验报文正确性，并调用对应报文的接收处理函数，见下表：

报头 | 报文内容 | 调用函数名

0x51 、 0x52 、 0x53 | 3个频率通道的 频率数据 | void frequency_callback(int channel, WavePara freq)

0x59 | 电池电量状态 | void battery_callback(BatteryStatus Batt)

0x5F | 3个频率通道的 使能指令 | void channel_enable_callback(boolean[] channelEnable)

使用该函数时，只需将输入数据流以 byte[] 形式传递给函数，为应对并非 byte[] 中所有 byte 均
为有效数据的情况，需要在函数第二个参数中指定输入的 byte[] 包含的有效数据长度，用法如

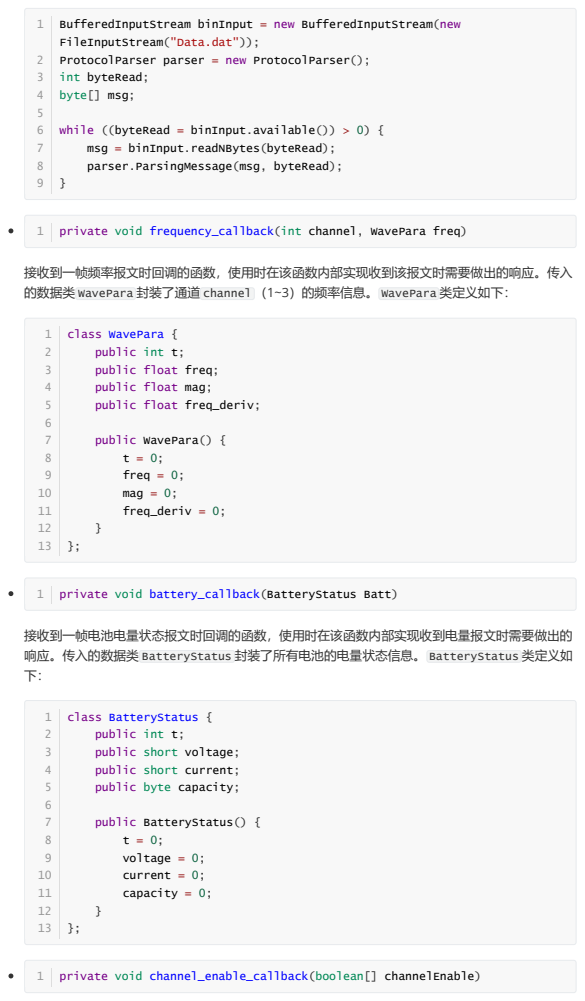
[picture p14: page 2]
private void frequency_callback(int channel, WavePara freq); public WavePara() {; t = 0; freq = 0;; mag = 0; freq_deriv = 0;; private void battery_callback(BatteryStatus Batt); public BatteryStatus() {; voltage = 0;; current = 0;; capacity = 0;; private void channel_enable_callback(boolean[] channelEnable)

BufferedInputStream binInput = new BufferedInputStream(new
FileInputStream("Data.dat"));
ProtocolParser parser = new ProtocolParser();
int byteRead;
byte[] msg;
while ((byteRead = binInput.available()) > 0) {
msg = binInput.readNBytes(byteRead);
parser.ParsingMessage(msg, byteRead);

接收到一帧频率报文时回调的函数，使用时在该函数内部实现收到该报文时需要做出的响应。传入
的数据类 WavePara 封装了通道 channel （1~3）的频率信息。 WavePara 类定义如下：

class WavePara {
public int t;
public float freq;
public float mag;
public float freq_deriv;

接收到一帧电池电量状态报文时回调的函数，使用时在该函数内部实现收到电量报文时需要做出的
响应。传入的数据类 BatteryStatus 封装了所有电池的电量状态信息。 BatteryStatus 类定义如

class BatteryStatus {
public short voltage;
public short current;
public byte capacity;

## 接收到一帧电池电量状态报文时回调的函数。该函数供嵌入式系统调用，响应手机端上位机发来的 通道使能指令，Android端可不关注，保持该函数为空。

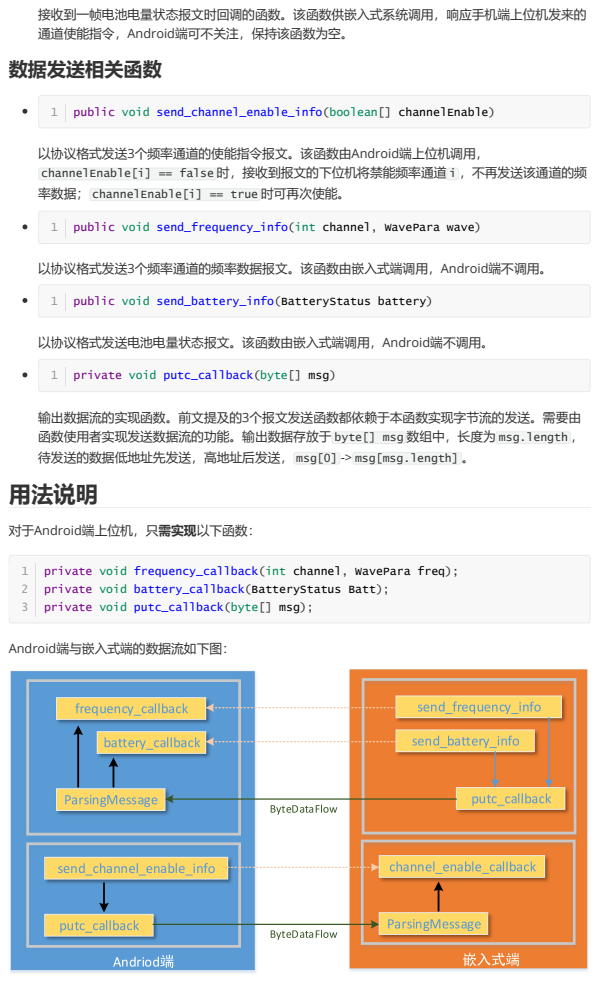
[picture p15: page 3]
数据发送相关函数; 以协议格式发送3个频率通道的频率数据报文。该函数由嵌入式端调用，Android端不调用。; 对于Android端上位机，只需实现以下函数：; Android端与嵌入式端的数据流如下图：; public void send_channel_enable_info(boolean[] channelEnable); public void send_frequency_info(int channel, WavePara wave); public void send_battery_info(BatteryStatus battery); private void putc_callback(byte[] msg)

以协议格式发送3个频率通道的使能指令报文。该函数由Android端上位机调用，
channelEnable[i] == false 时，接收到报文的下位机将禁能频率通道 i ，不再发送该通道的频
率数据； channelEnable[i] == true 时可再次使能。

以协议格式发送电池电量状态报文。该函数由嵌入式端调用，Android端不调用。

输出数据流的实现函数。前文提及的3个报文发送函数都依赖于本函数实现字节流的发送。需要由
函数使用者实现发送数据流的功能。输出数据存放于 byte[] msg 数组中，长度为 msg.length ，
待发送的数据低地址先发送，高地址后发送， msg[0] -> msg[msg.length] 。
用法说明

private void frequency_callback(int channel, WavePara freq);
private void battery_callback(BatteryStatus Batt);
private void putc_callback(byte[] msg);

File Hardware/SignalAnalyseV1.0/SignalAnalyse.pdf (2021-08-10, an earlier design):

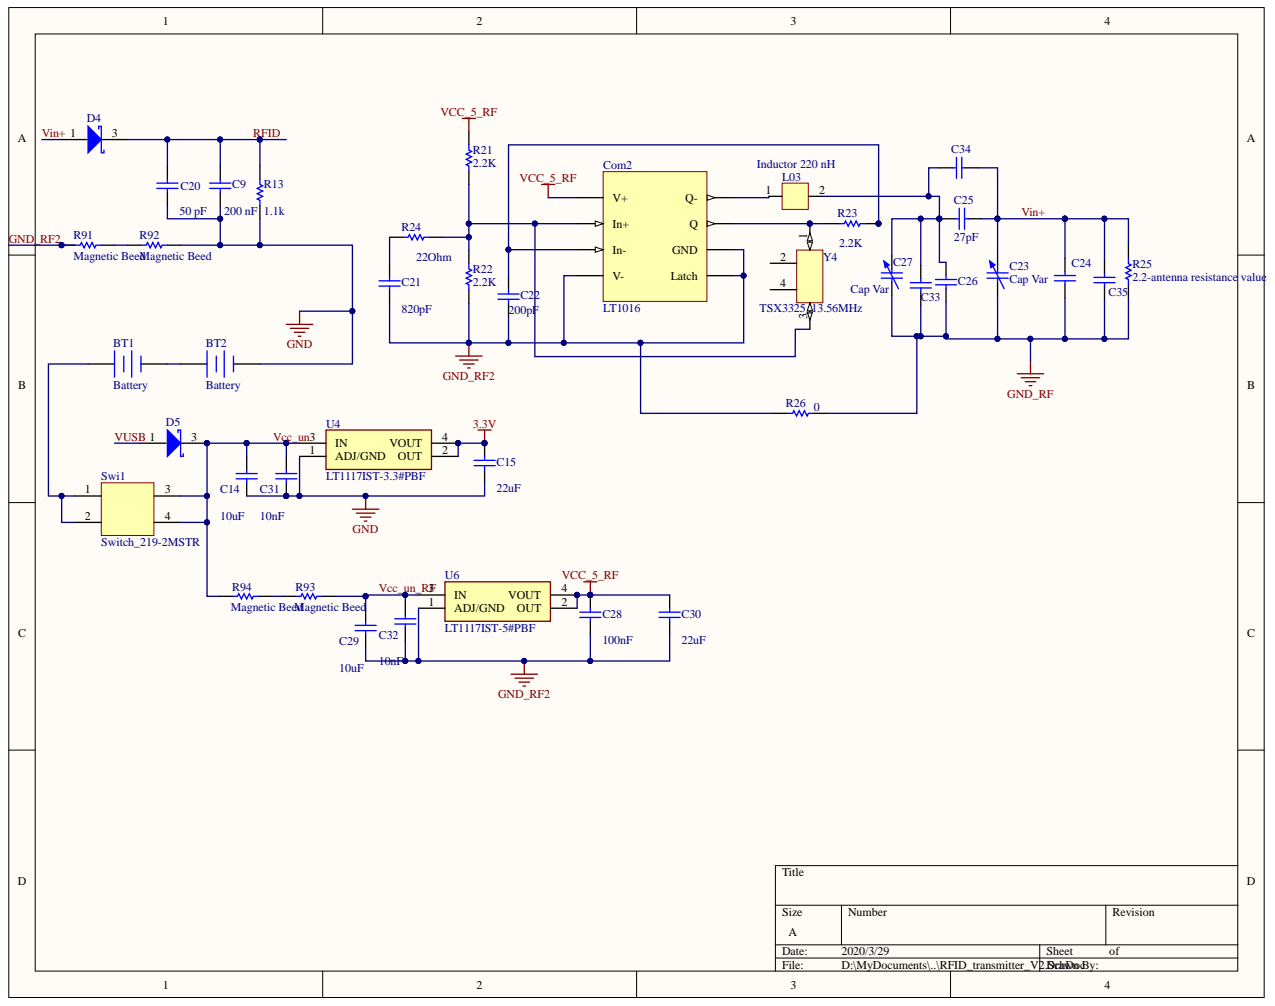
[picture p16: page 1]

In-GND
V-Latch | 2

Size A | Number | Revision

Date: 2020/3/29 | Sheet of
File: D:\MyDocuments\..\RFID_transmitter_V2.SchD Drawn By: oc

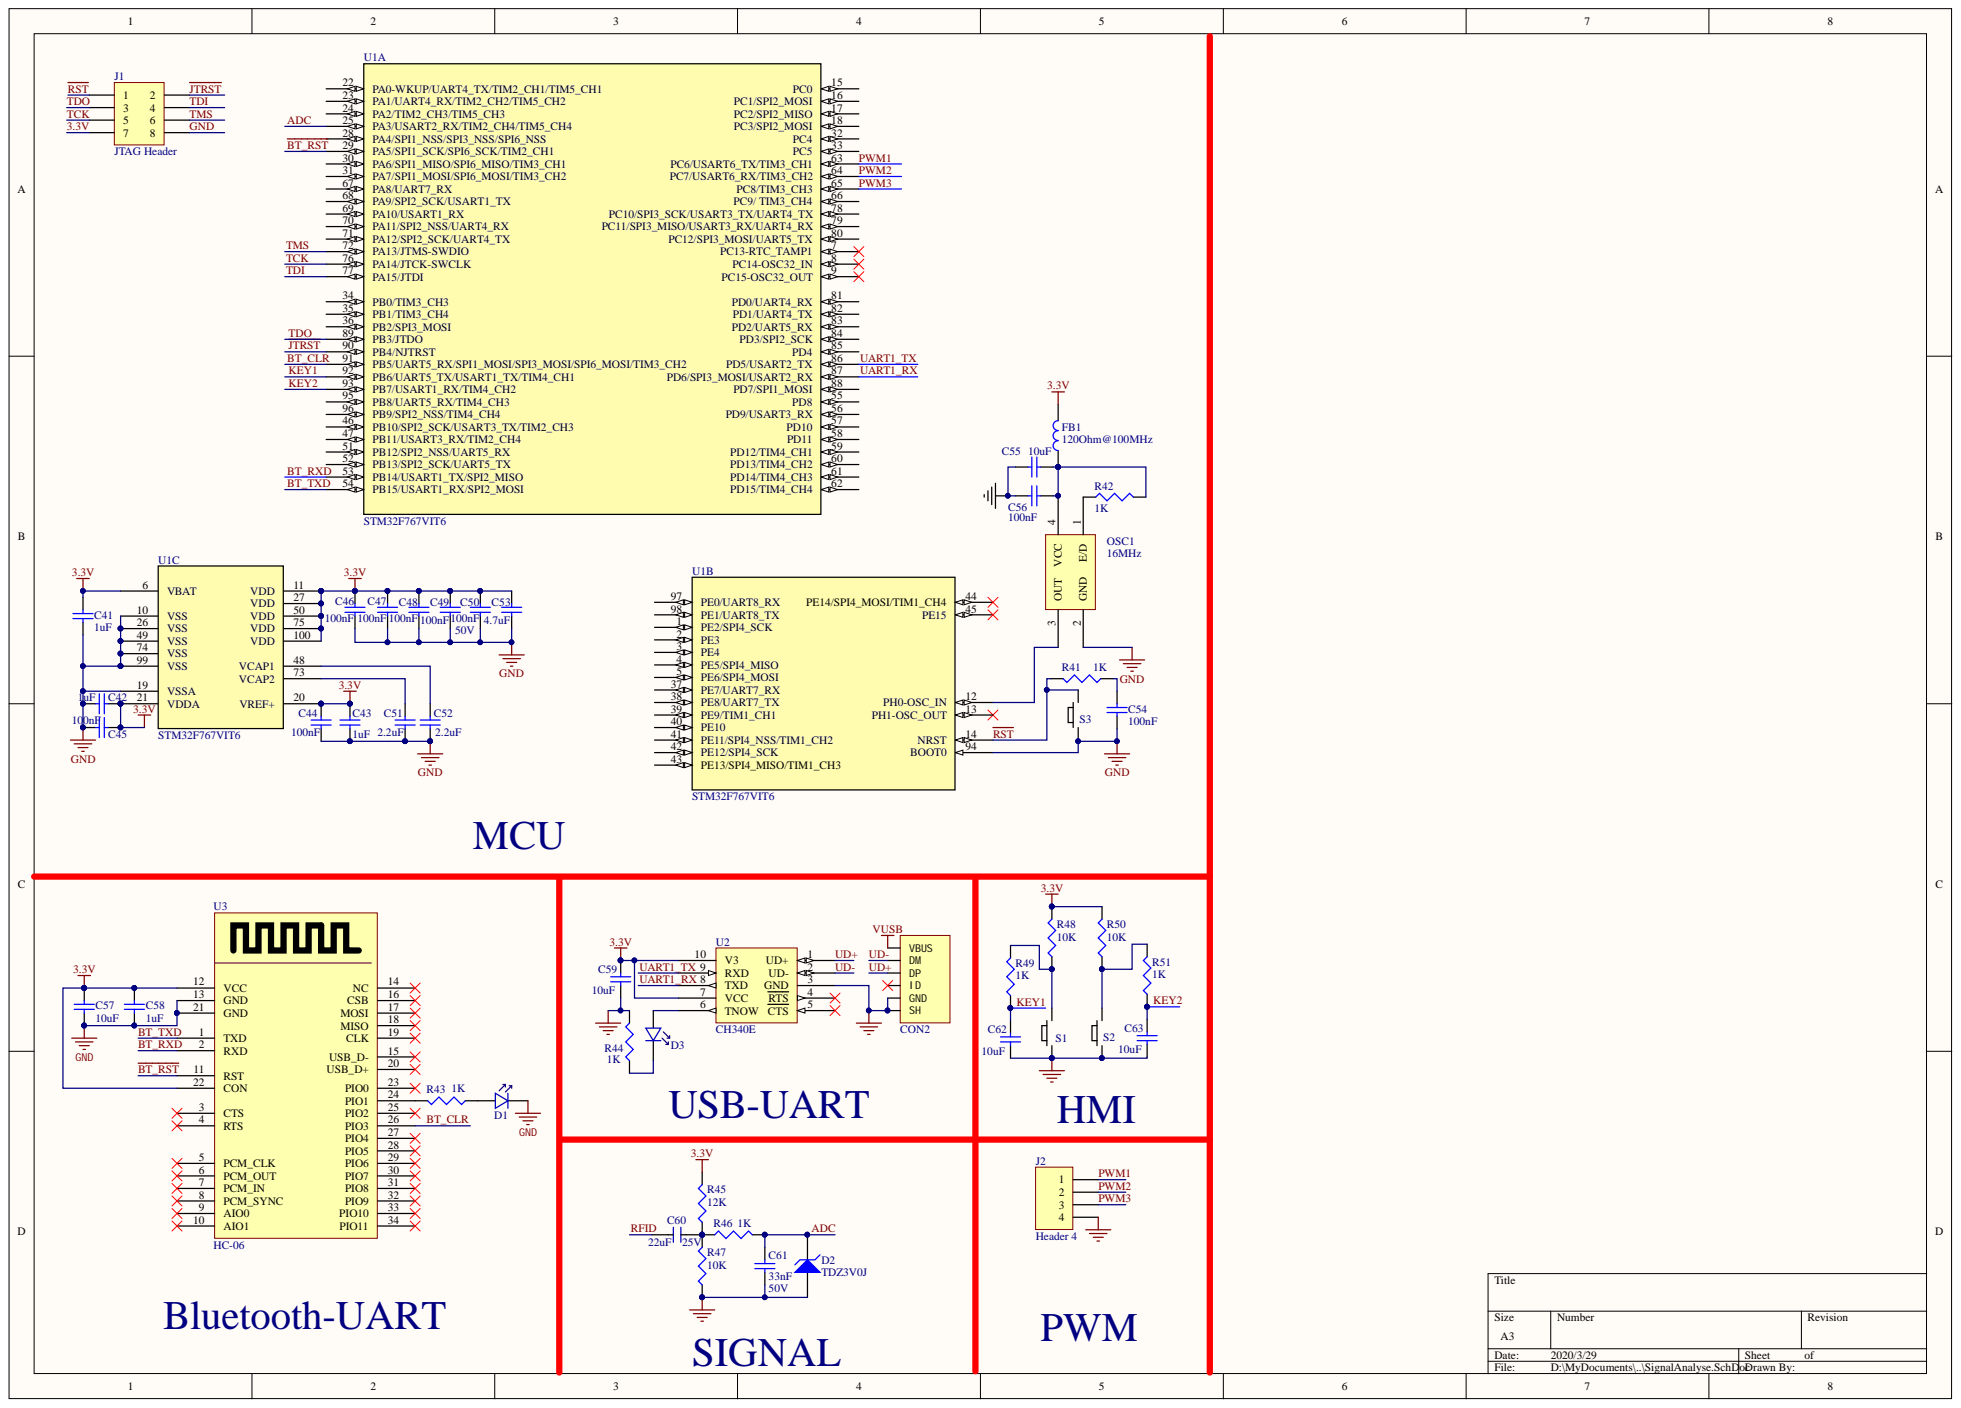
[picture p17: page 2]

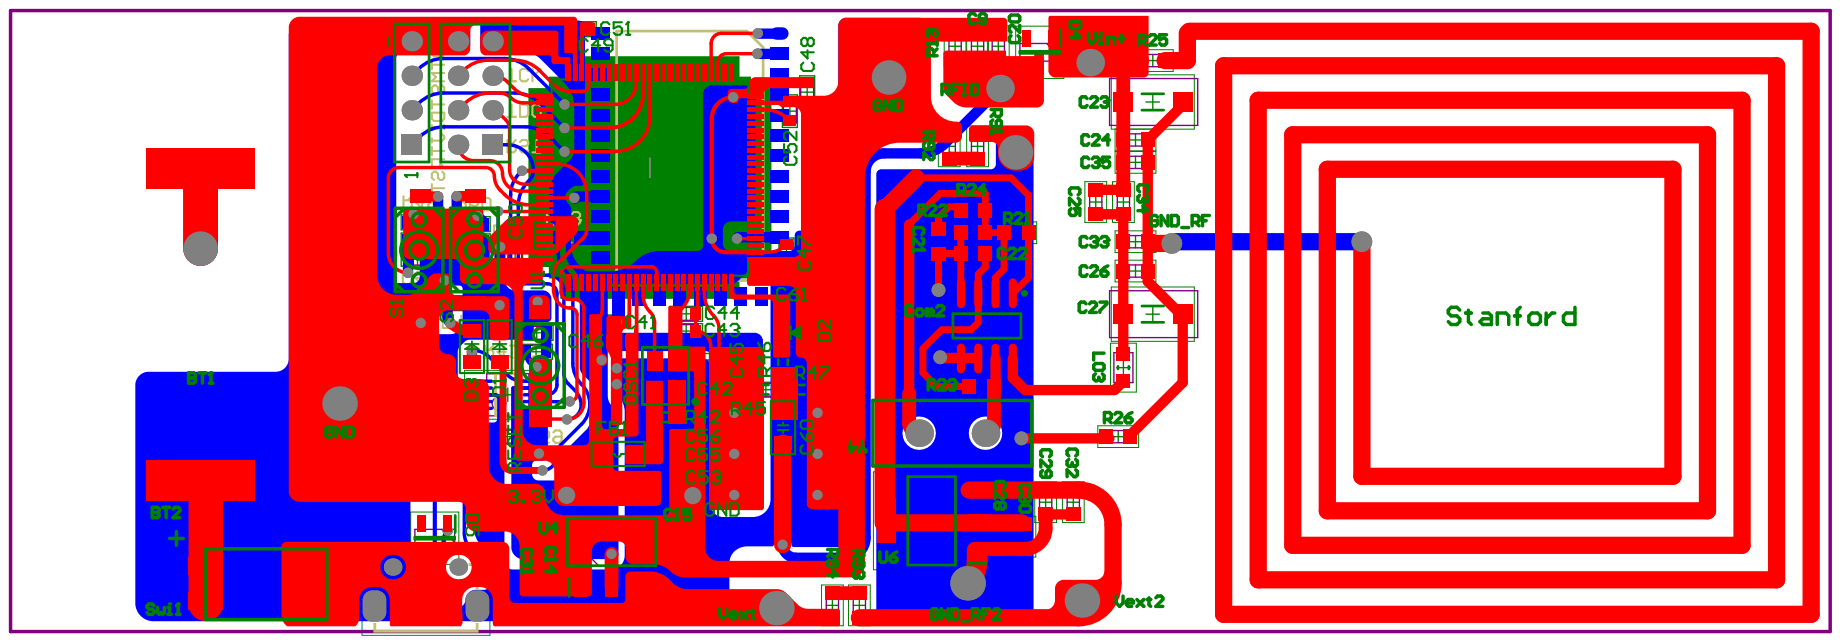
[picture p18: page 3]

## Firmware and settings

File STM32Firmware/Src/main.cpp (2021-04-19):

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

/* Includes ------------------------------------------------------------------*/
#include "main.h"
#include "adc.h"
#include "dma.h"
#include "tim.h"
#include "usart.h"
#include "Message.h"
#include "gpio.h"
#include "Scheduler.h"
#include "HMI.h"
#include "arm_math.h"
#include "DSP.h"
/* USER CODE BEGIN Includes */
#include "SysTime.h"
/* USER CODE END Includes */


/* USER CODE BEGIN PV */
extern DMA_HandleTypeDef hdma_adc1;

/* USER CODE END PV */


/**
  * @brief  The application entry point.
  * @retval int
  */
int main(void)
{
  /* Enable I-Cache---------------------------------------------------------*/
  SCB_EnableICache();

  /* Enable D-Cache---------------------------------------------------------*/
  //SCB_EnableDCache();

  /* MCU Configuration--------------------------------------------------------*/

  /* Reset of all peripherals, Initializes the Flash interface and the Systick. */
  HAL_Init();

  /* Configure the system clock */
  SystemClock_Config();

  /* Initialize all configured peripherals */
  MX_GPIO_Init();

  MX_DMA_Init();
  MX_USART1_UART_Init();
  MX_USART2_UART_Init();
  MX_TIM3_Init();
  MX_ADC1_Init();
  MX_TIM2_Init();

  /* USER CODE BEGIN 2 */
  USART_Puts(&huart2, "Hello world!\nFirmware version: V1.0, ");
  USART_Puts(&huart2, "compile time: ");
  USART_Puts(&huart2, __DATE__);
  USART_Puts(&huart2, ", ");
  USART_Puts(&huart2, __TIME__);
  USART_Puts(&huart2, ".\n");
  //USART_Putchars(&huart1, Greetings, sizeof(Greetings));

  InitFilter();
  /* USER CODE END 2 */

  /* Infinite loop */
  /* USER CODE BEGIN WHILE */
  while (1)
  {
    /* USER CODE END WHILE */

    /* USER CODE BEGIN 3 */
    run_scheduler();
    ExecuteBtnRoutine();
    signal_downsampling();
    UpdateMessage();
    /*while (USART2_RX_Stream.size() > 0)
      USART_Putc(&huart1, USART2_RX_Stream.pop_front());
    while (USART1_RX_Stream.size() > 0)
      USART_Putc(&huart2, USART1_RX_Stream.pop_front());*/
  }
  /* USER CODE END 3 */
}

/* USER CODE BEGIN 4 */

/* USER CODE BEGIN EFP */

/* USER CODE END 4 */
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


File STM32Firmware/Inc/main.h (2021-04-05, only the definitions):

#define S1_Pin GPIO_PIN_6
#define S1_GPIO_Port GPIOB
#define S2_Pin GPIO_PIN_7
#define S2_GPIO_Port GPIOB
#define BT_RST_Pin GPIO_PIN_5
#define BT_RST_GPIO_Port GPIOA
#define BT_CLR_Pin GPIO_PIN_5
#define BT_CLR_GPIO_Port GPIOB

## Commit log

2021-04-07 Disable DCache for proper DMA Function.
2021-04-07 Disable DCache for proper DMA operation.
2021-04-15 Complete message C++ realization and Bluetooth-USB-UART loopback.
2021-04-16 Packetstream parsing bug fixed.
    [DSP.cpp, HMI.cpp, Message.cpp]
2021-04-17 Fixed virtual signal generator sin function invalid input bugs.
    [DSP.cpp]
2021-04-18 Send battery info to UART.
2021-04-18 Revise capacity estimation function.
2021-05-06 Add .vscode file.
    [FrequencyAnalyseV3.0协议一览.xlsx]
2021-05-06 1. Accomplished Java implementation of ProtocolParser; 2. Fixed bug in function ParsingMessage(), pass correct byte length to void MessageStream::recv_packet(uint8_t head, uint8_t *payload, uint32_t 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
    [FrequencyAnalyseV3.0协议一览.xlsx]
2021-05-07 Add pictures and visio file to illustrate the ProtocolParser usage.
    [FrequencyAnalyseV3.0协议一览.xlsx]
2021-05-12 Fixed bug when sending battery info, change payload array size.
    [Message.cpp]
2021-08-10 Revise README.md file.
    [Bill of Materials for SignalAnalyseV3.0.xlsx, Oscillation_Power part_BOM.xlsx, Pick Place for SignalAnalyse.csv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]

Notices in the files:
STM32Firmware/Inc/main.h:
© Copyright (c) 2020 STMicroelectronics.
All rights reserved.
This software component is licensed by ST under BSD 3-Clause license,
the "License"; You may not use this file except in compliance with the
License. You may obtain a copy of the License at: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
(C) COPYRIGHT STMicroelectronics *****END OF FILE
